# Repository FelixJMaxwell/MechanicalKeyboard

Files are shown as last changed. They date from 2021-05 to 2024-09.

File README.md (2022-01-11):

# Teclados Mecanicos
Repositorio creado para contener proyectos relacionados al super costoso hobby de los teclados mecanicos.

Siguiendo los tutoriales por parte de ai03 y MasterZen
 - [PCB Designer Guide](https://wiki.ai03.com/books/pcb-design/chapter/pcb-designer-guide)
 - [Designing a keyboard from scratch](https://www.masterzen.fr/2020/05/03/designing-a-keyboard-part-1/)

No considero ninguna de los dos anterior mejor que el otro pues se complementan en diferentes aspectos.

<br>
<br>
  
# Macropad

Foot print con marca para cada tecla  
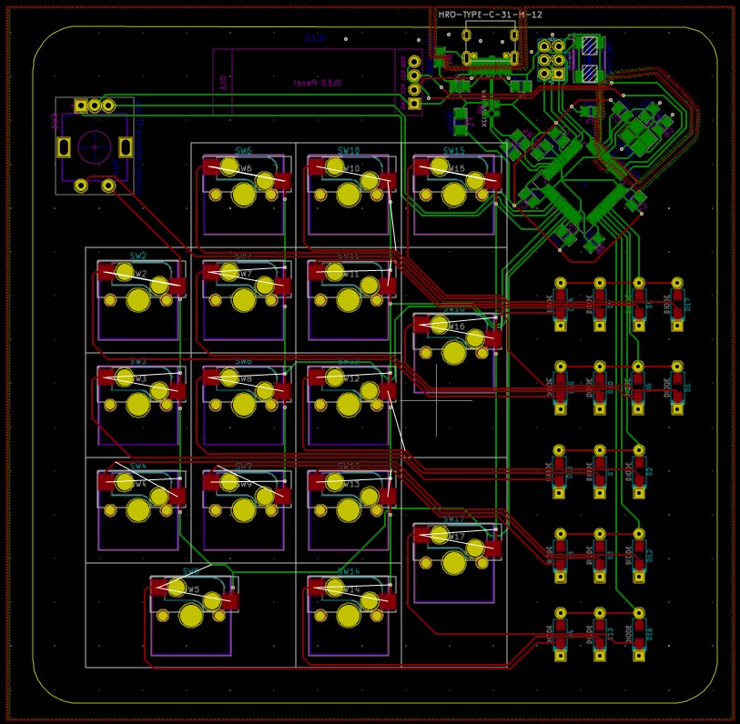
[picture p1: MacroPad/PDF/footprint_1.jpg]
  
Footprint sin marca para cada tecla  
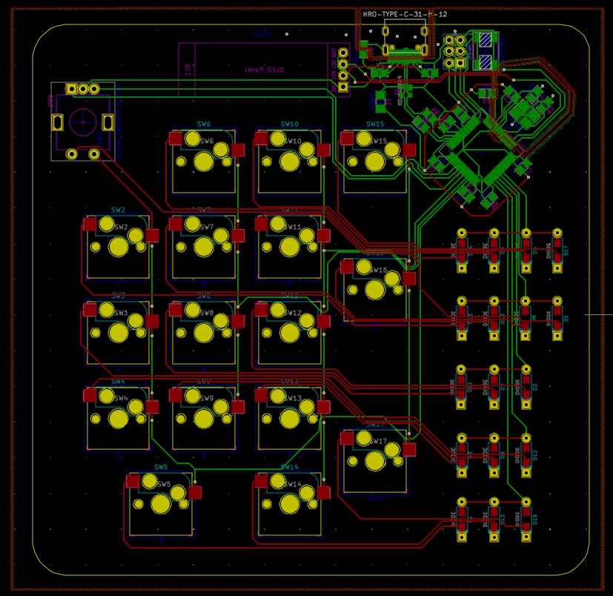
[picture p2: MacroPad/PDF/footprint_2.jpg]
  

<br>
<br>
  
# Split keyboard
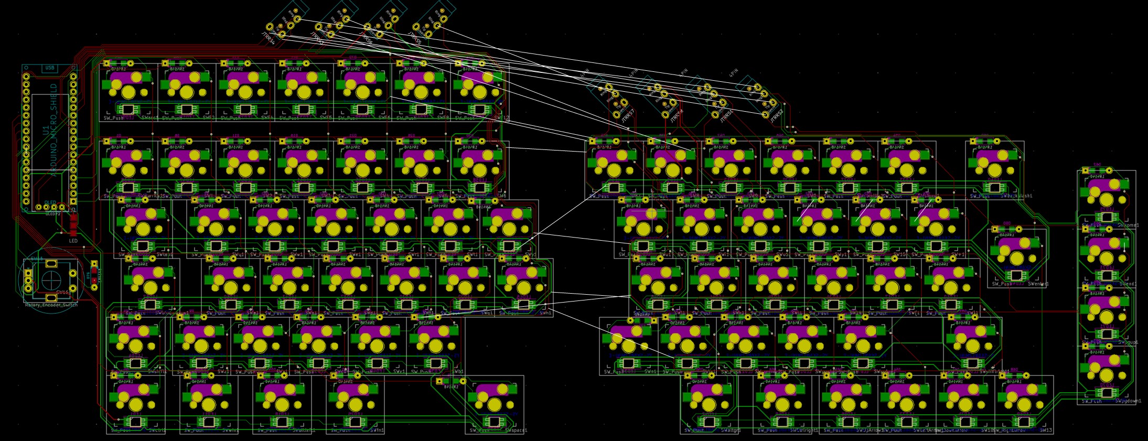
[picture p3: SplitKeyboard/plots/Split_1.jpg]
  

<br>
<br>

# Cuarenta Keyboard
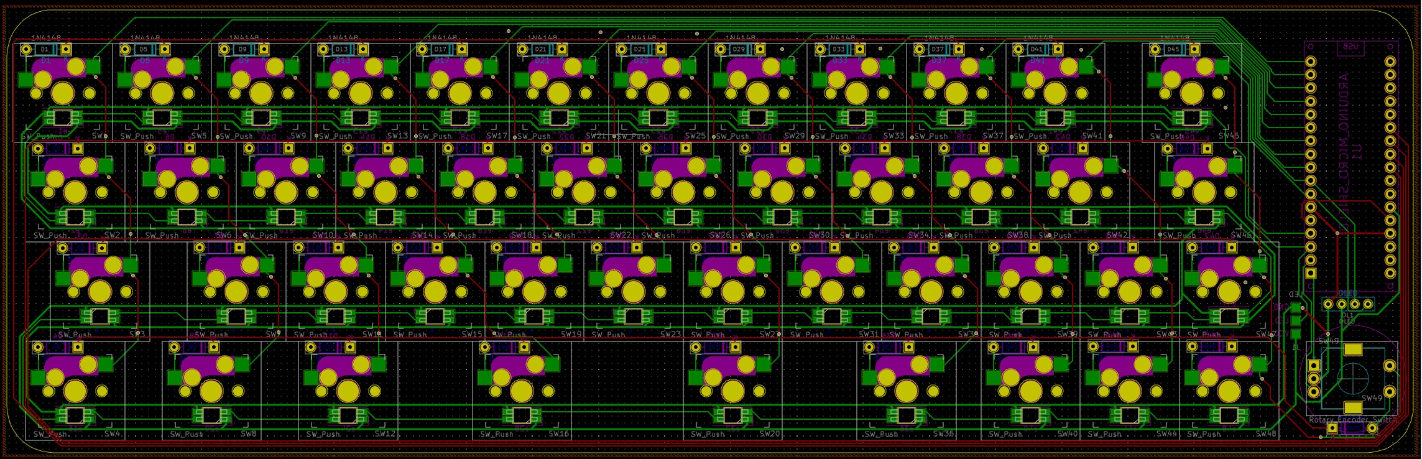
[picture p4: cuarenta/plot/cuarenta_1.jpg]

La PCB anterior contiene tres errores

1.- Un switch no esta conectado al diodo correspondiente
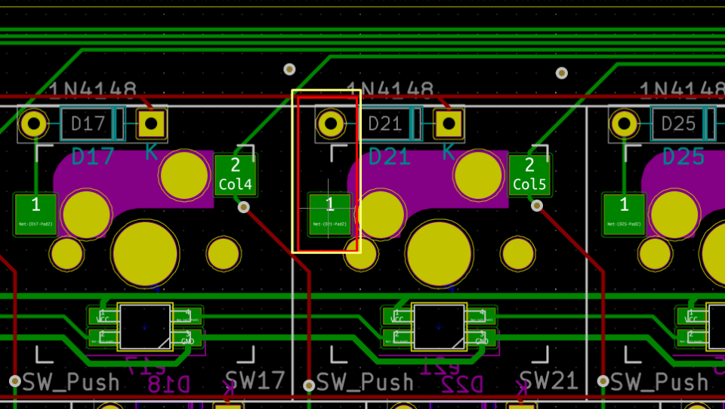
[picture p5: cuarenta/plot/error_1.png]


2.- Hizo falta poner una via para conectar tres switches a su columna correspondiente
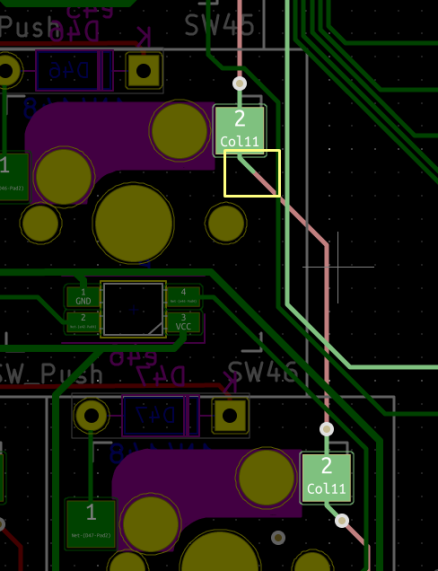
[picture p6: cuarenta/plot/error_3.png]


3.- El encoder esta conectado en la misma posicion del ultimo switch de su columna, se de agregar a una nueva fila.
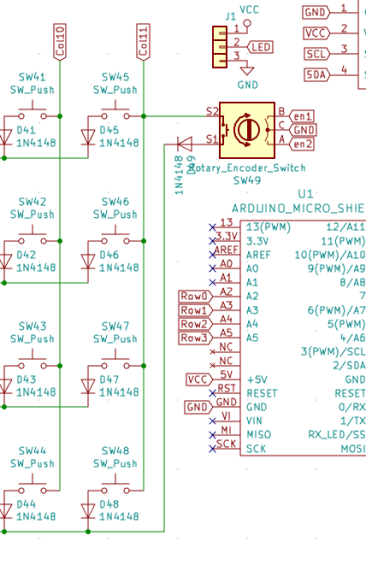
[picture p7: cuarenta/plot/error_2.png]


Esta PCB la envie a producción con JLCPCB antes de ver los errores por lo que llegaron cinco placas todas con los tres errores anteriores.
errores

Errores en la PCB, corregidos con puentes usando barillas de laton.

Encoder + switch conectado a otro pin del Arduino micro al mismo tiempo que se puentean los adaptadores para hotswap 
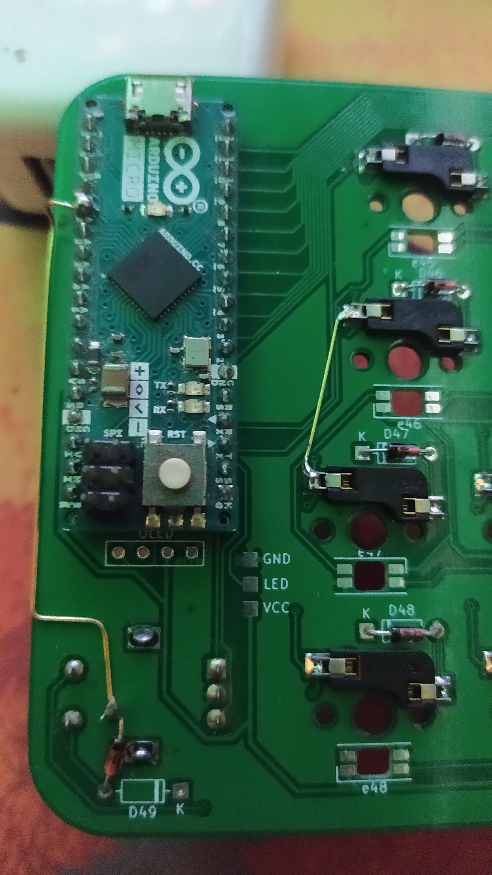
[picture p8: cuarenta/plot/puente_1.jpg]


Se conecta el adaptador hotswap al diodo correspondiente
errores

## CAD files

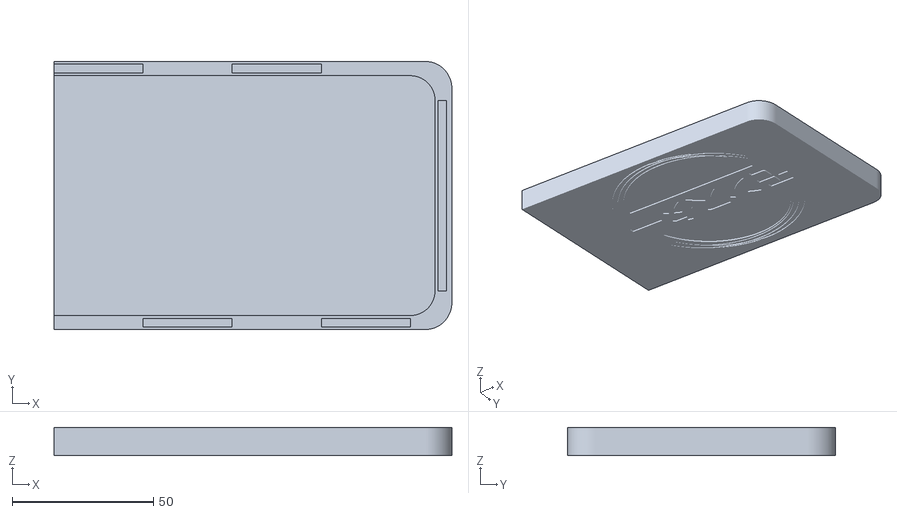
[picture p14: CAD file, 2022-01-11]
cuarenta/plot/case_101.stl
140.9 x 94.8 x 10.0

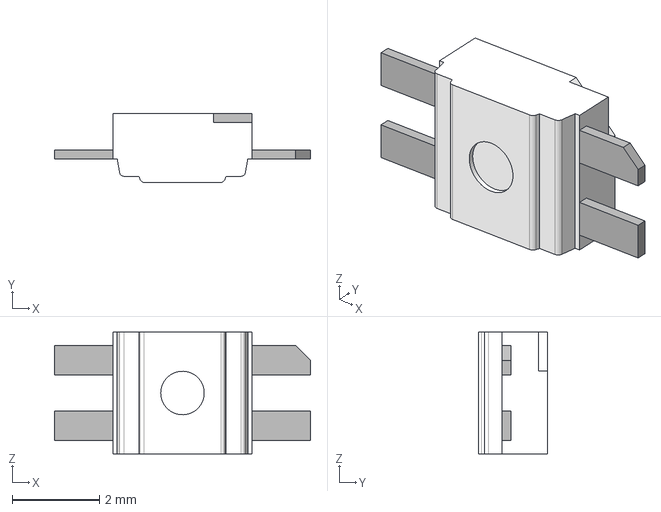
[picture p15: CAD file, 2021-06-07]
Kicad Footprints/SK6812MINI-E v1.step
5.88 x 1.58 x 2.80 mm

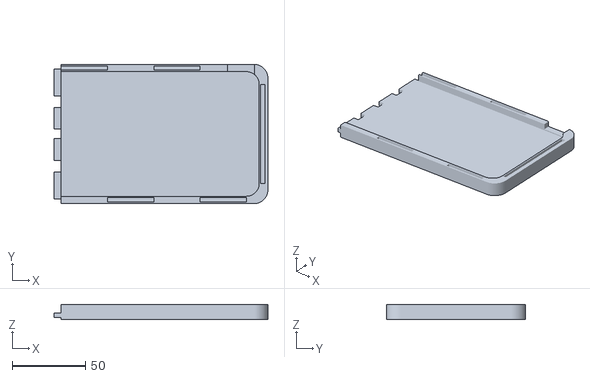
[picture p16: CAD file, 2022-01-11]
cuarenta/plot/case_100.stl
145.8 x 94.8 x 10.0

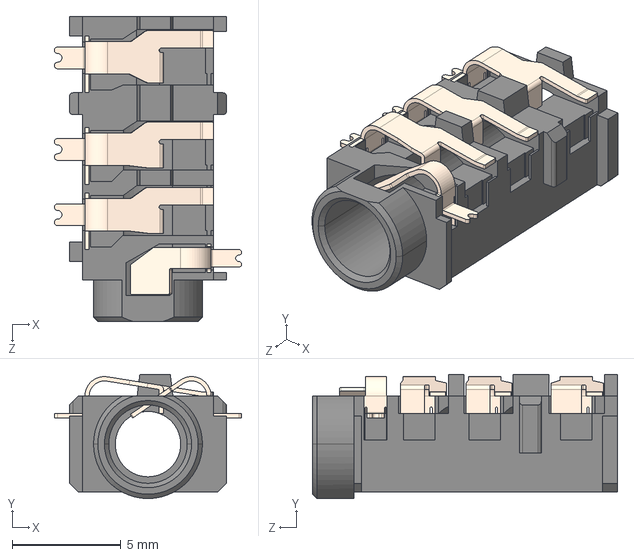
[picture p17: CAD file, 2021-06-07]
Kicad Footprints/CUI_SJ-43614-SMT-TR.step
8.60 x 5.70 x 14.0 mm

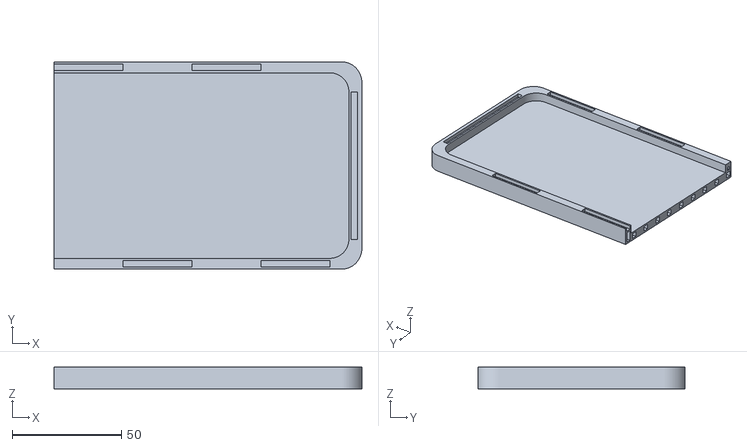
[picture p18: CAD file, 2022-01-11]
cuarenta/plot/case_3.stl
140.9 x 94.8 x 10.0

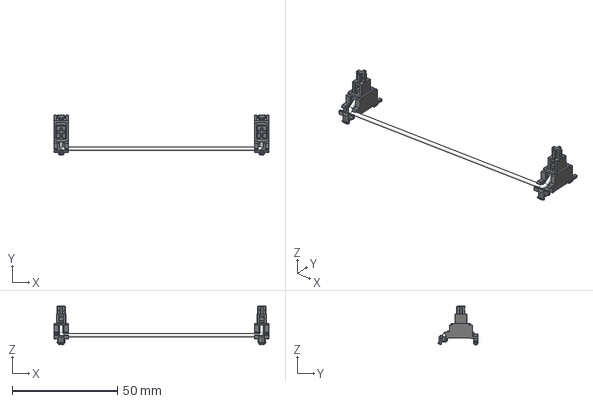
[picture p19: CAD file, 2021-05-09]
Kicad Footprints/Stabilizer_Cherry_MX_6u.step
102.1 x 19.2 x 18.3 mm

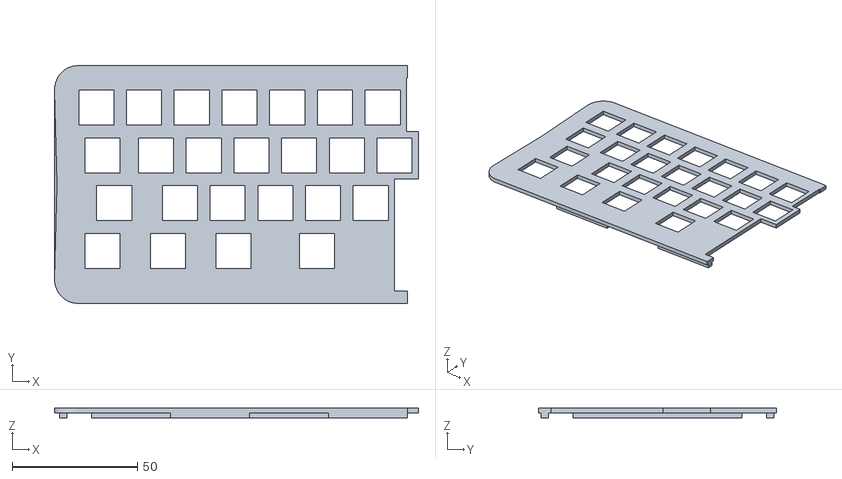
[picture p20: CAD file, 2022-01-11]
cuarenta/plot/Case_1.stl
145.3 x 94.8 x 4.00

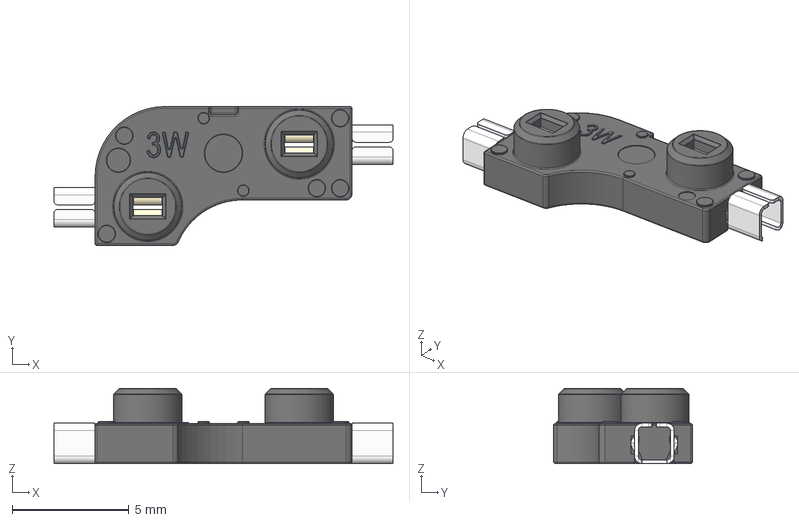
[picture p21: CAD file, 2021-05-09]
Kicad Footprints/SW_Hotswap_Kailh.step
14.5 x 5.95 x 3.22 mm

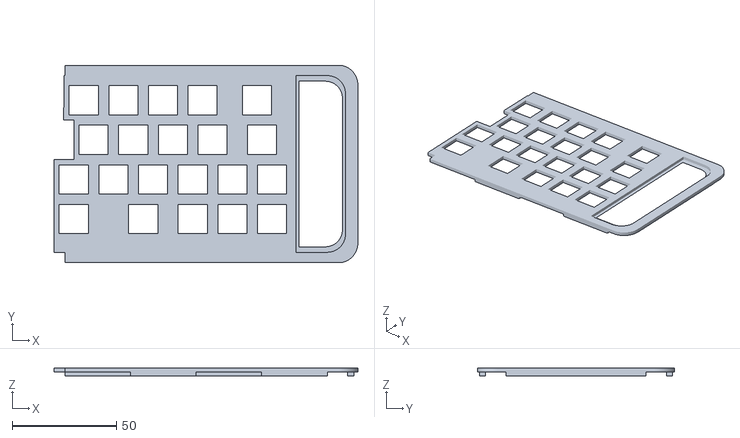
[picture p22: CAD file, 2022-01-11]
cuarenta/plot/case_2.stl
146.1 x 94.8 x 4.00

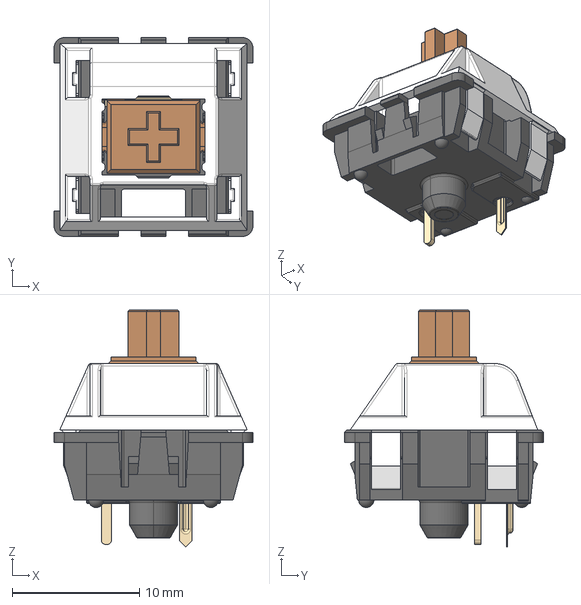
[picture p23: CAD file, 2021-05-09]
Kicad Footprints/SW_Cherry_MX_Plate.step
15.6 x 15.6 x 18.6 mm

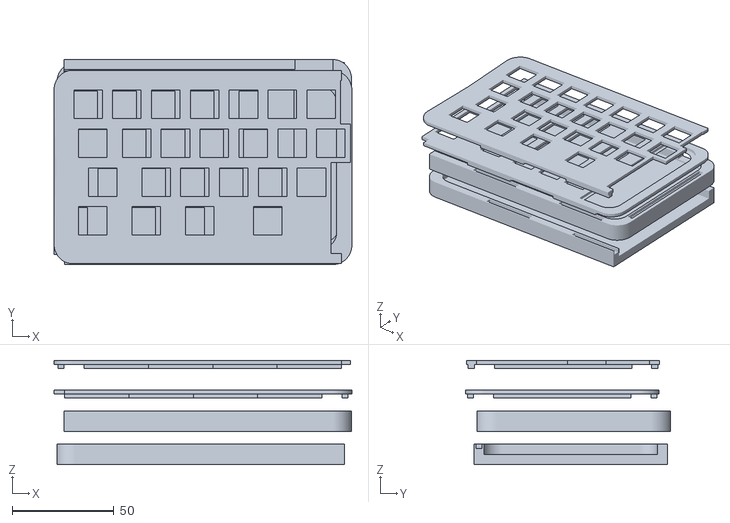
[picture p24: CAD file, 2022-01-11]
cuarenta/plot/Case.stl
146.1 x 100.5 x 51.2

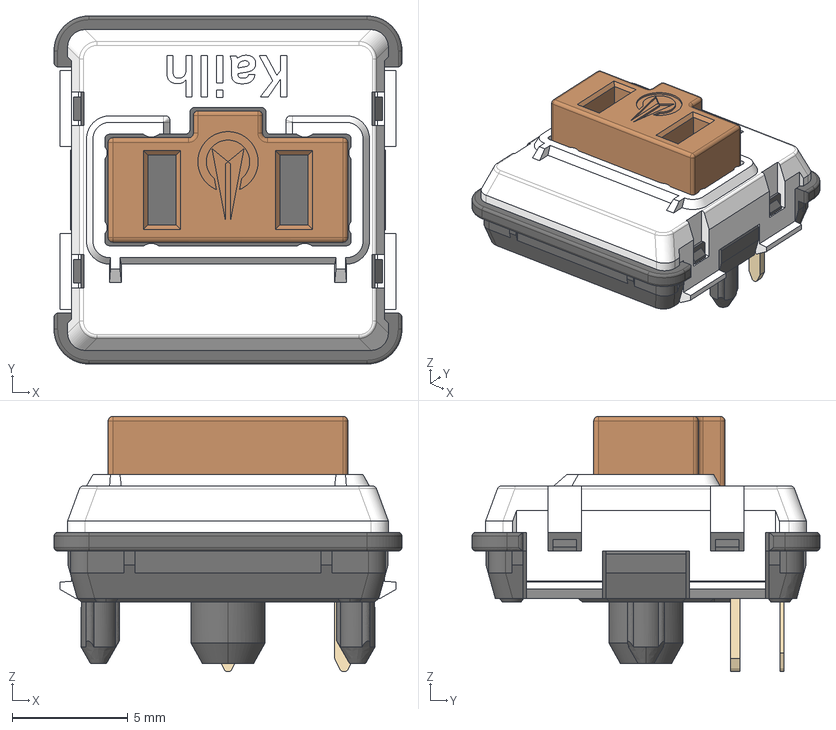
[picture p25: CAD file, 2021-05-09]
Kicad Footprints/SW_Kailh_Choc_V1.step
15.0 x 15.0 x 11.0 mm

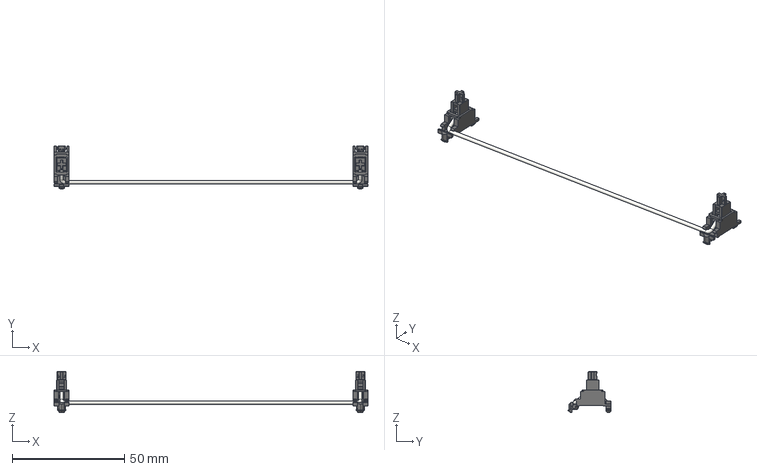
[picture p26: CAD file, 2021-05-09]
Kicad Footprints/Stabilizer_Cherry_MX_8u.step
140.1 x 19.2 x 18.3 mm

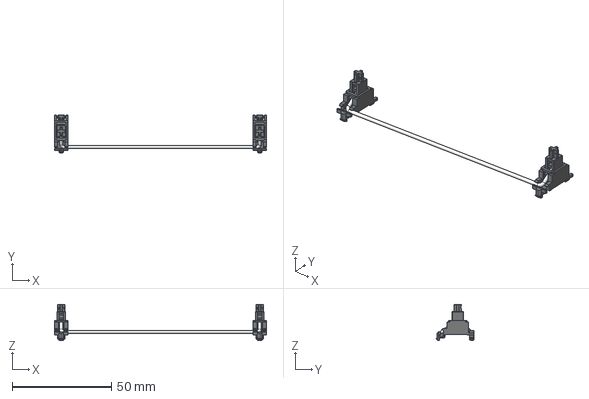
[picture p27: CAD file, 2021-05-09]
Kicad Footprints/Stabilizer_Cherry_MX_6_25u.step
106.8 x 19.2 x 18.3 mm

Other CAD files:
cuarenta/plot/case_b.stl
cuarenta/plot/case_4.stl
Kicad Footprints/Stabilizer_Cherry_MX_7u.step
Kicad Footprints/Stabilizer_Cherry_MX_6.25u.FCStd
Kicad Footprints/1N4148.step
Kicad Footprints/CherryMX Switch.step
Kicad Footprints/D_SOD-123 Soldered.f3z
Kicad Footprints/D_SOD-123 Soldered.step
Kicad Footprints/D_SOD-123.step
Kicad Footprints/HRO TYPE-C-31-M-12.step
Kicad Footprints/JST-SR-3.step
Kicad Footprints/JST-SR-4.step
Kicad Footprints/Kailh-CherryMX-Socket.step
Kicad Footprints/MX Series-Cherry Key.step
Kicad Footprints/Molex-0548190519.step
Kicad Footprints/OLED Module with Pins Soldered.step
Kicad Footprints/OLED Module with Soldered.step
Kicad Footprints/OLED-Module-with-Pins.step
Kicad Footprints/PJ-3200B.step
Kicad Footprints/PJ-320A.step
Kicad Footprints/PJ320A Soldered.step
Kicad Footprints/PJ320A.step
Kicad Footprints/ProMicro.step
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

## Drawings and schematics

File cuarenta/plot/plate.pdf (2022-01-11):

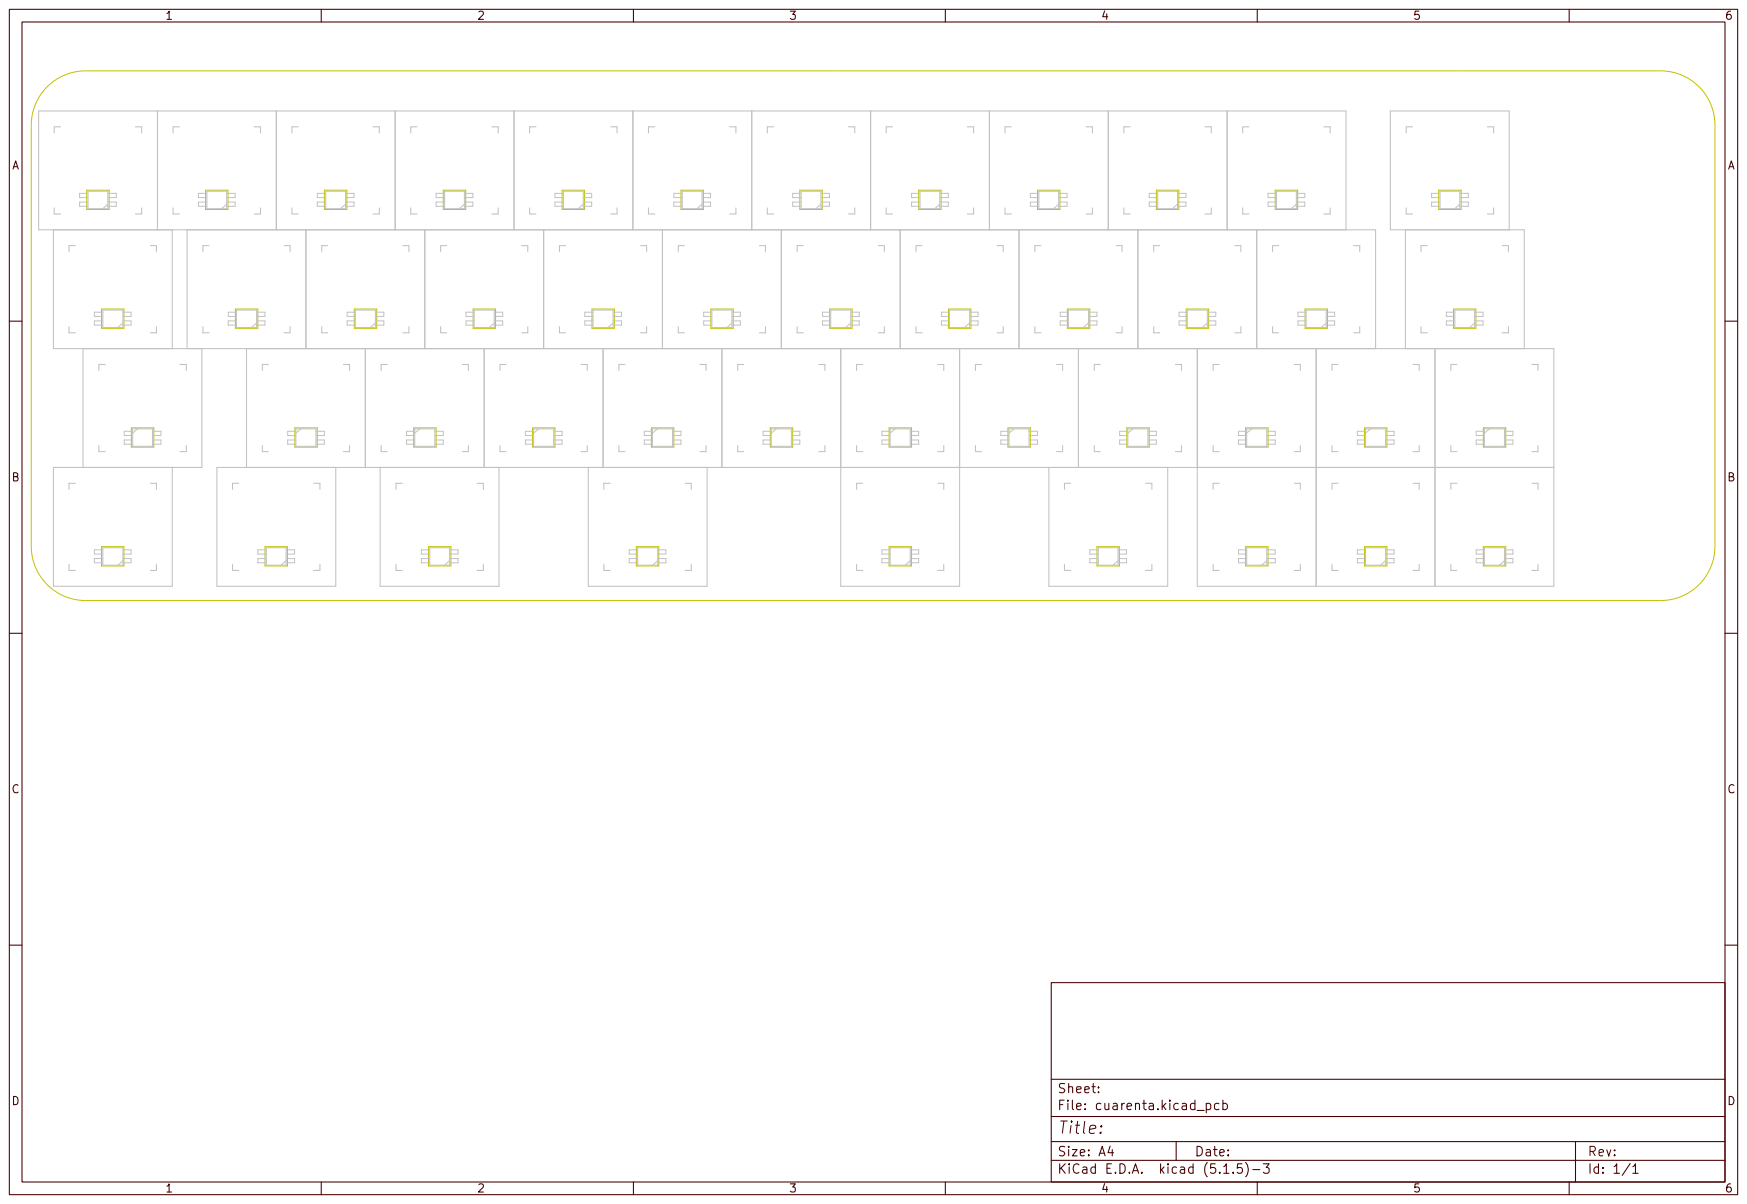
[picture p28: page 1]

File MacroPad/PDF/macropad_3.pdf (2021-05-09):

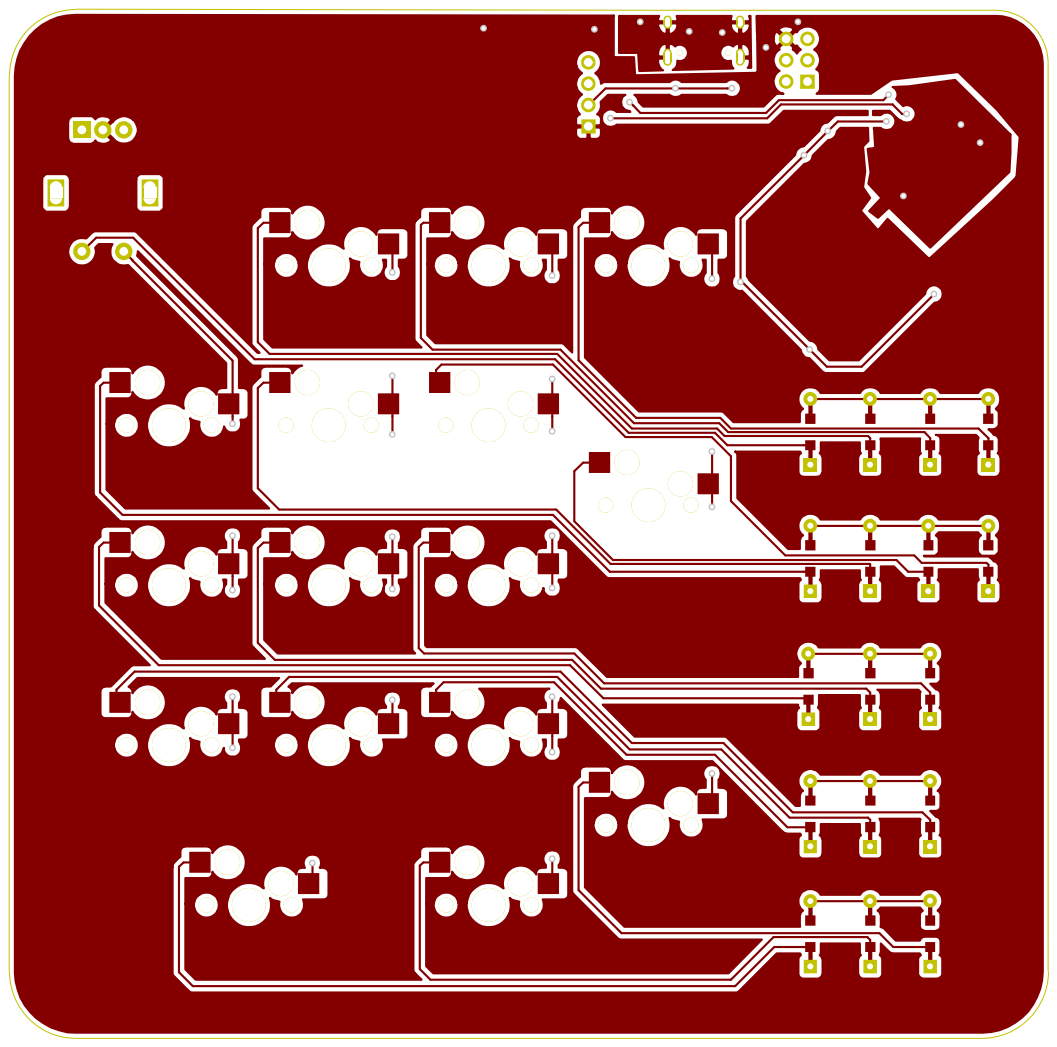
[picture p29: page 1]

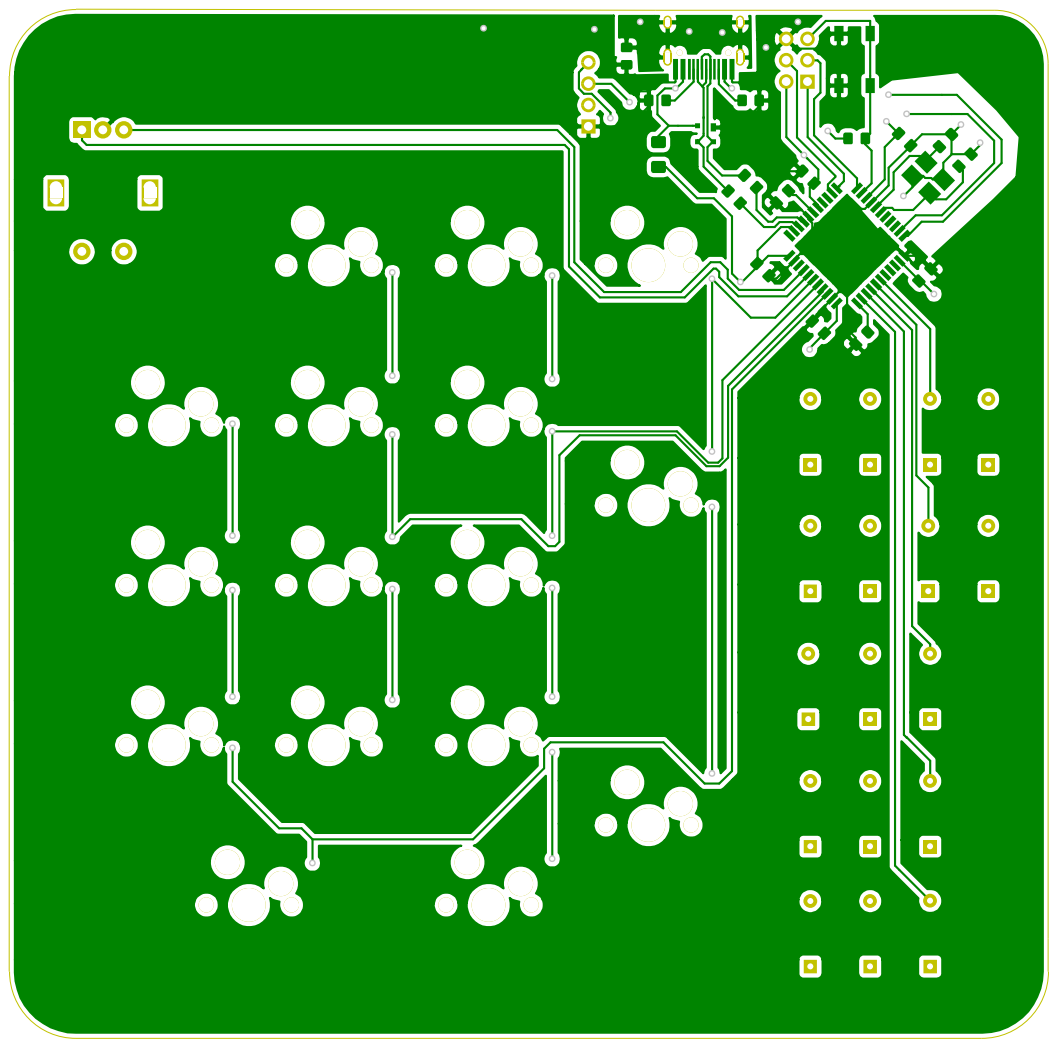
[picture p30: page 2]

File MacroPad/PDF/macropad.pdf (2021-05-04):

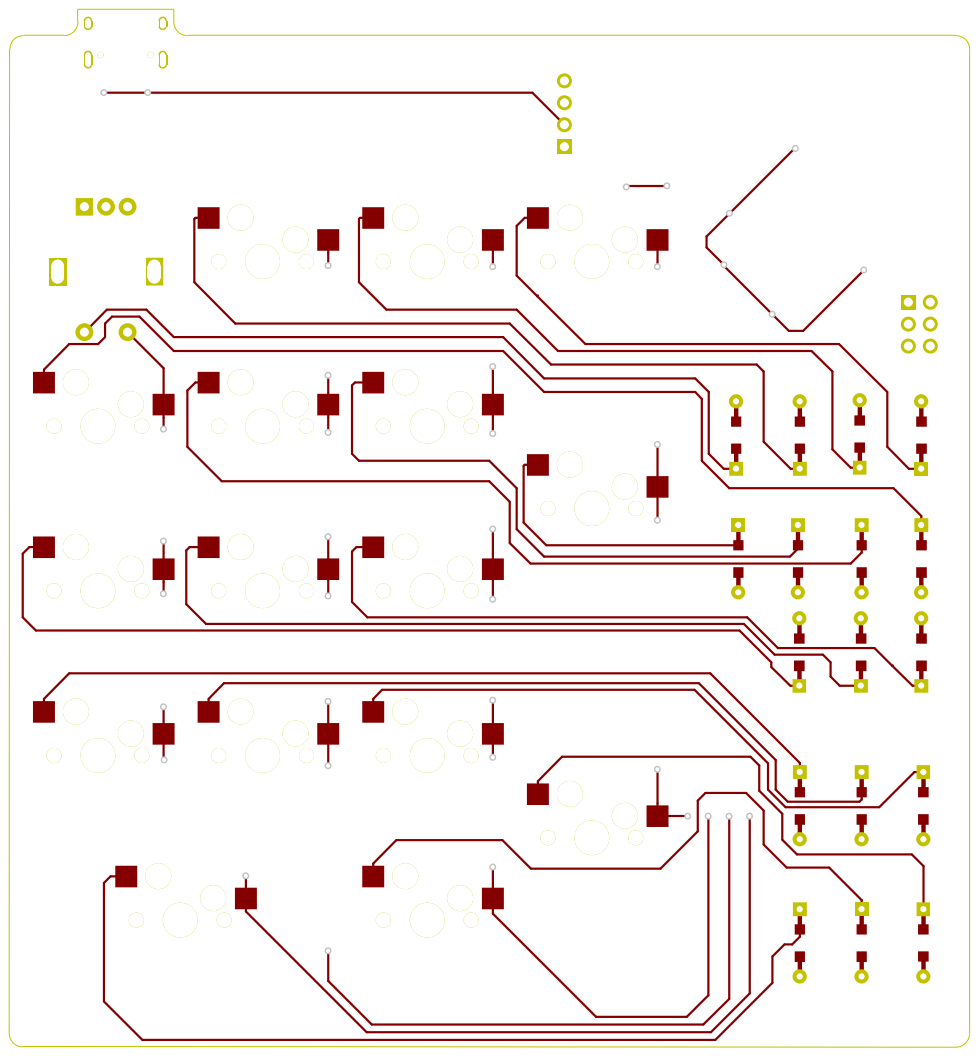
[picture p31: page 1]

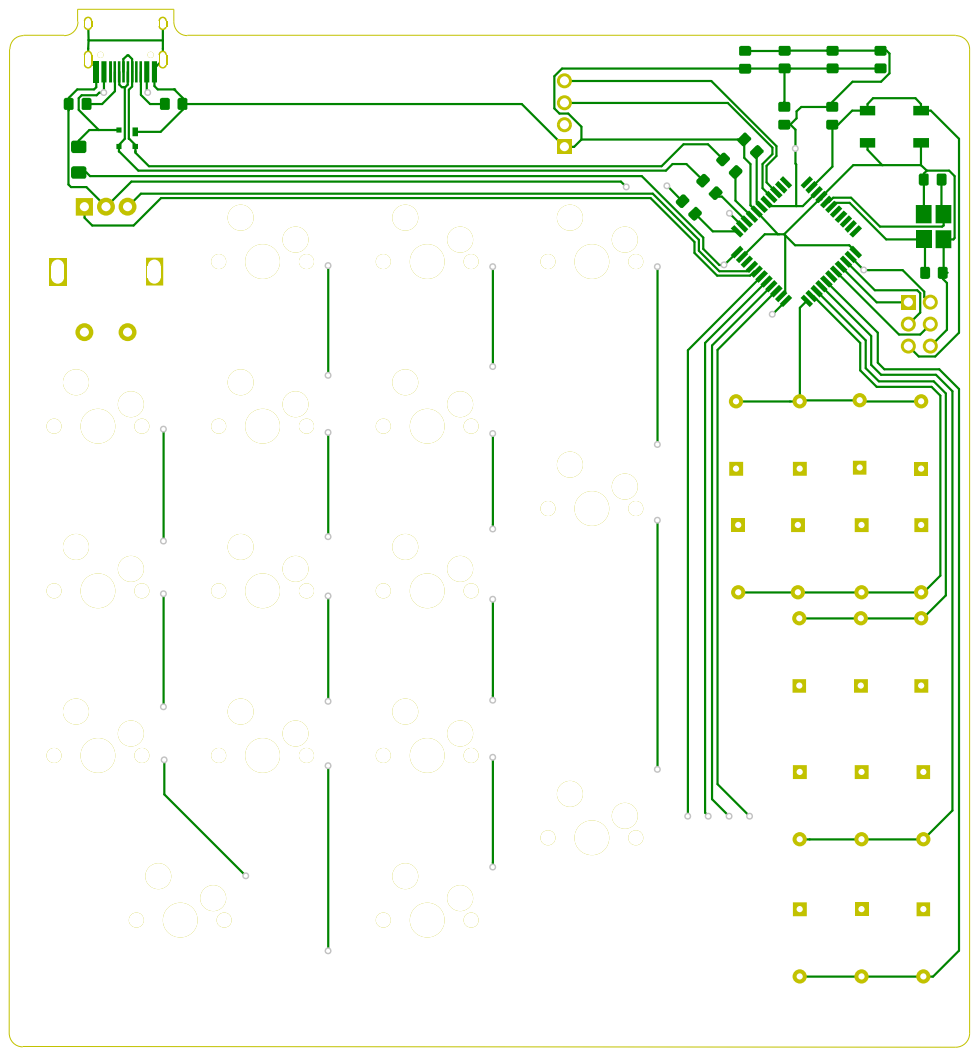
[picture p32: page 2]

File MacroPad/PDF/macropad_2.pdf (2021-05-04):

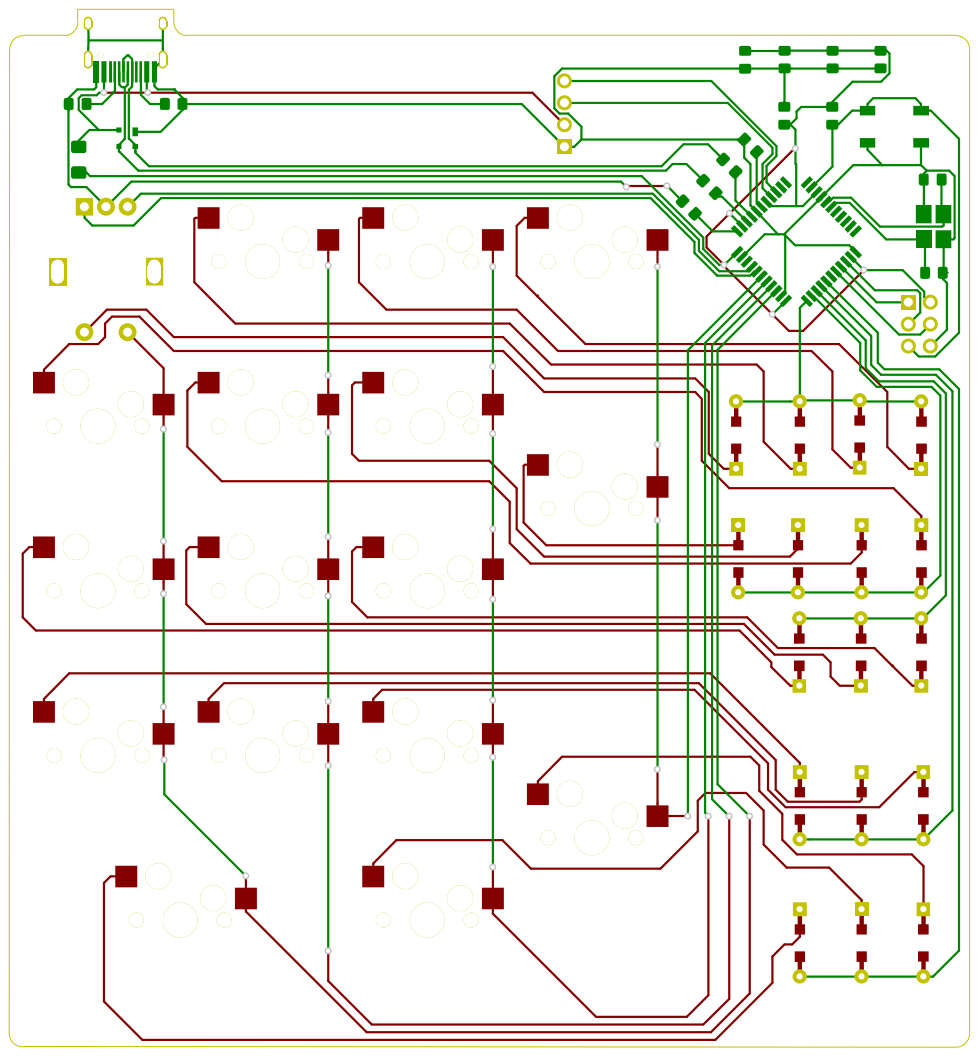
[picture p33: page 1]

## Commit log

2021-05-04 rutas v2
    [HRO TYPE-C-31-M-12.step, JST-SR-3.step, JST-SR-4.step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]
2021-05-05 cambiando rutas
    [MacroPad.kicad_pcb, MacroPad.sch]
2021-05-08 ultimas partes
    [MacroPad.kicad_pcb, MacroPad.sch]
2021-05-09 final final
    [MacroPad-B_Cu.gbr, MacroPad-B_Mask.gbr, MacroPad-B_Paste.gbr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]
2021-05-09 cambio de footprint
    [MacroPad.kicad_pcb, MacroPad.sch]
2021-05-09 footprints preview
2021-05-10 cambiado tamaño pistas y vcc oled
    [MacroPad.kicad_pcb, MacroPad.sch]
2021-06-07 New Footprints
    [CUI_SJ-43614-SMT-TR.step, HRO TYPE-C-31-M-12.step, PJ-320A.step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]
2021-06-07 Folder Modification
    [CUI_SJ-43614-SMT-TR.step, HRO TYPE-C-31-M-12.step, JST-SR-3.step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]
2021-06-07 image pcbnew added
2021-08-08 minivan with RGB knob and led display
    [CUI_SJ-43614-SMT-TR.step, HRO TYPE-C-31-M-12.step, JST-SR-3.step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]
2021-09-11 agregada imagen de pcbcnew cuarenta
2021-09-11 agregada evidencia de los errores
2021-09-11 PCB en produccion agregada mas errores
2022-01-11 Agregado 40%
    [Case.blend, Case.obj, Case.stl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]
2022-01-13 footprints revueltas
    [1N4148.step, CUI_SJ-43614-SMT-TR.step, CherryMX Switch.step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]
2022-01-13 restaurados archivos 40%
    [cuarenta.kicad_pcb, cuarenta.kicad_sch]
2022-02-03 Endgame D:
    [stain-B_Cu.gbl, stain-B_Mask.gbs, stain-Edge_Cuts.gm1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]
2023-05-01 EndGame 30042023
    [EndGame.kicad_pcb, EndGame.kicad_sch, stain.kicad_sch]
